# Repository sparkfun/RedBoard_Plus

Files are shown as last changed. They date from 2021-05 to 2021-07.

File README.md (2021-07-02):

SparkFun RedBoard Plus
============================

SparkFun RedBoard Plus (https://www.sparkfun.com/products/18158)

[*SparkFun RedBoard Plus (DEV-18158)*](https://www.sparkfun.com/products/18158)

At SparkFun we continually like to innovate, update, and improve even when it comes to our very own development boards. The SparkFun RedBoard Plus is an Arduino-compatible development board that has everything you need in an Arduino Uno with *many* extra perks. The best part about the RedBoard Plus is that it utilizes our handy Qwiic Connect System which means no soldering or shields are required to connect it to the rest of your system!

We've applied every lesson we've learned about making a better Arduino Uno and created the RedBoard Plus! The SparkFun RedBoard Plus has all of the hardware peripherals you know and love: 22x Digital I/O pins with 6x PWM pins, 8x analog pins, UART, I<sup>2</sup>C, SPI, and external interrupts. We've also broken out the SDA, SCL and IOREF pins that showed up on the Arduino Uno R3 footprint, so the RedBoard Plus is compatible with future shields (if you choose to use them). Two additional analog pins are included for A6 and A7.

The USB-to-serial is now done with a *reversible* USB-C connector with through hole anchoring and the ubiquitous CH340G requiring fewer driver installs. The power portion of the RedBoard Plus has been optimized: we use the AP2112 3.3V voltage regulator to provide up to 600mA to daisy chain multiple Qwiic boards and sensors, with full thermal and reverse circuit protection, and added extra decoupling capacitance to increase the sensitivity of the ADC readings. We've also increased the PTC from 500mA to 2A. We've decreased the brightness of the power LED, pin 13 LED, and the TX/RX LEDs from blinding to just perfect.

We've included 3.3V voltage translation and a [Qwiic connector](https://www.sparkfun.com/qwiic) to the edge of the board to allow for quick and seamless connection to our ever-growing line of I<sup>2</sup>C based [Qwiic products](https://www.sparkfun.com/qwiic#products). Jumpers are included on the board for the A4 and A5 pins which are tied directly to the I<sup>2</sup>C bus and can be used to disconnect the logic level converters from the pins. 

For more advanced users we've added an I/O voltage switch also known as the "Red Squirrel" switch (because they are the one [who petitioned for the mod](https://www.sparkfun.com/products/retired/15296#comment-5d78452ec6a6ff5bfc77dba7)). Now you can easily select the GPIO voltage between 3.3V or 5V with just your finger. This is extremely handy if you have a shield or 3.3V sensitive devices, such as an SPI interface, that needs protecting. Worried about accidentally flipping the switch? A piece of tape will lock it in place!

We include clearly labeled PTH holes alongside the standard female headers. This makes it very easy to solder wires in place for a secure connection to make your project 'backpack safe' once you get it working. Solder pads are included on the bottom of the board for USB data pins D+/D- so you can embed your RedBoard Plus into a project and run an external USB connection. We've increased the height of the reset button. This doesn't sound like much, but everyone who's touched it loves the improvement. 

The SparkFun RedBoard Plus can be programmed over a USB-C cable using the Arduino IDE: Just plug in the board, select "**Arduino UNO**" from the board menu and you're ready to upload code! You can power the SparkFun RedBoard Plus over USB or through the barrel jack. The on-board power regulator can handle anything from 7VDC to 15VDC. Check out the related items below for a compatible wall-wart power supply.

Not sure which Arduino or Arduino-compatible board is right for you? Check out our [Arduino Buying Guide](https://www.sparkfun.com/arduino_guide)!

Repository Contents
-------------------
* **/Documentation** - Data sheets, additional product information
* **/Hardware** - Eagle design files (.brd, .sch)
* **/Production** - Production panel files (.brd)

Documentation
--------------
* **[Hookup Guide](https://learn.sparkfun.com/tutorials/1758)** - Basic hookup guide for the RedBoard Plus.

License Information
-------------------

This product is _**open source**_! 

Please review the LICENSE.md file for license information. 

If you have any questions or concerns on licensing, please contact technical support on our [SparkFun forums](https://forum.sparkfun.com/viewforum.php?f=152).

Distributed as-is; no warranty is given.

- Your friends at SparkFun.

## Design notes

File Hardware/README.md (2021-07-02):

SparkFun RedBoard Plus Design Files
=====================================

The .sch and .brd files hare are Eagle CAD schematic and PCB design files from SparkFun Electronics.
A freeware version of Eagle can be found [here](http://www.cadsoftusa.com/download-eagle/freeware/).

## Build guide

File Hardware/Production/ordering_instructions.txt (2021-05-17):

panel size, 374x132mm
PCB thickness, 1.6mm
number of layers, 2
soldermask color, Red
silkscreen color, White
oz copper, 1oz
finish, HASL lead free
stencils, top
pcs per panel, 10
min trace width, 0.2540mm / 0.0100in
min drill size, 0.3810mm / 0.0150in

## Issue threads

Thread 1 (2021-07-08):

Cap C18 too far from CH340G vcc pin

Hooziw, 2021-07-08:
Use as decoupling cap, C18 is too far form chip vcc
and DTR wire has 10mil width, normal was 12mil.

makin-stuff, 2021-07-09:
@Hooziw Thanks for the input and good catch! This issue will be addressed in the next version of this board.

Closed 2021-07-09.

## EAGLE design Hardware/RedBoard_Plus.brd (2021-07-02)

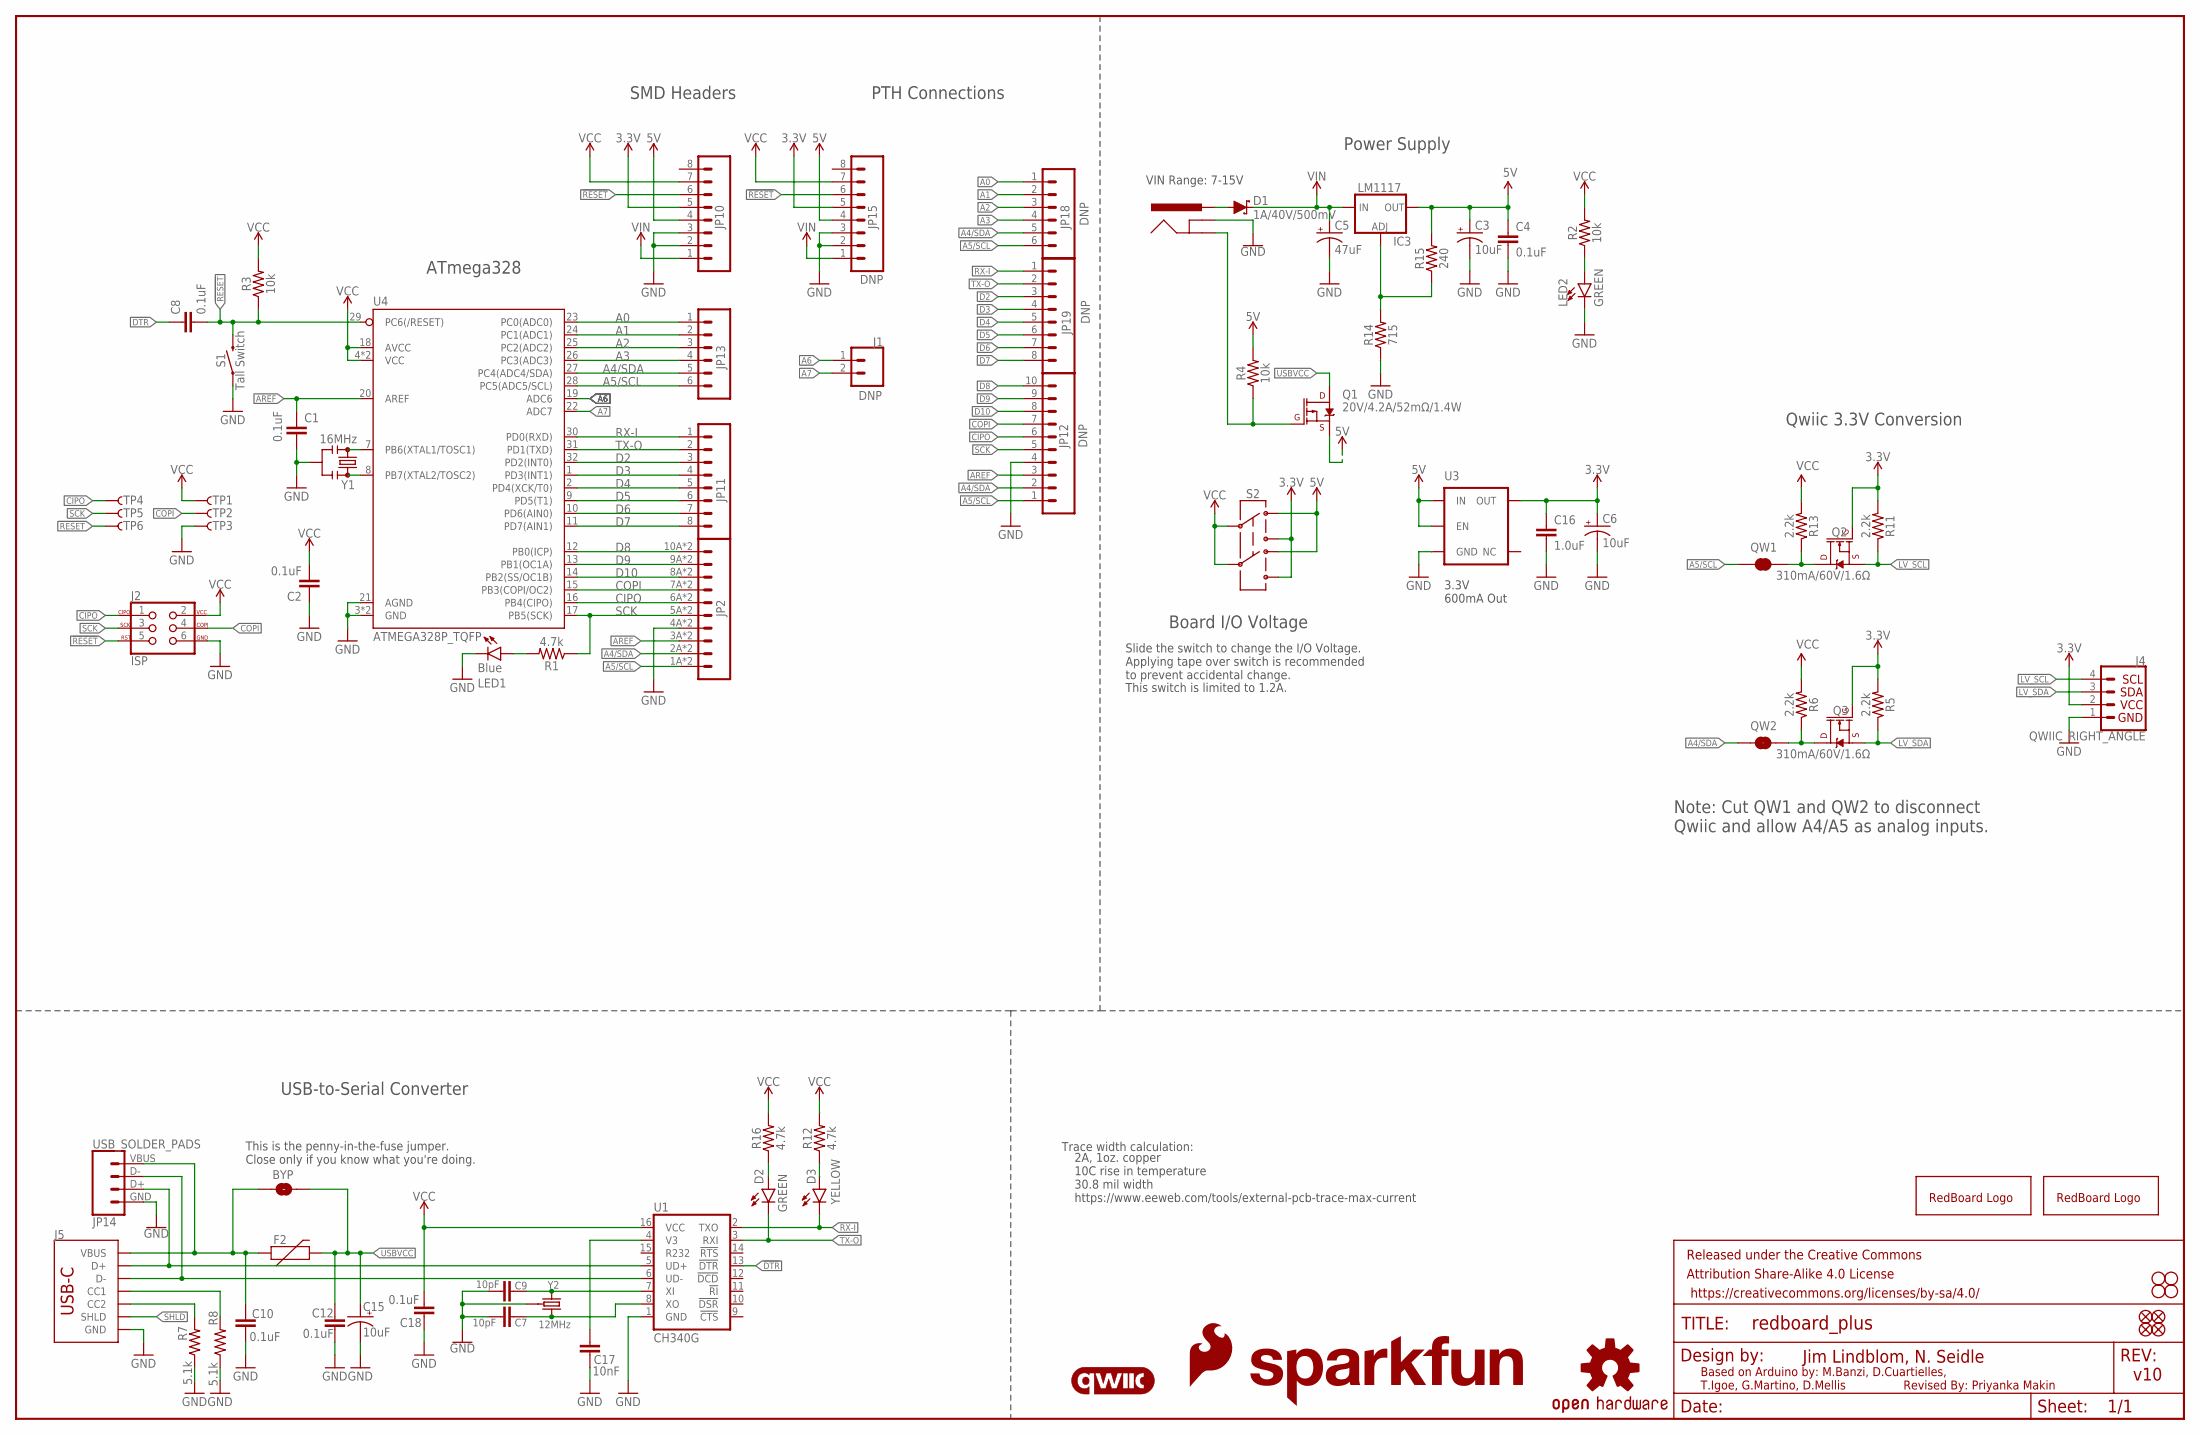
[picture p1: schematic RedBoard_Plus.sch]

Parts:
BYP: JUMPER-SMT_2_NO_SILK; SMT-JUMPER_2_NO_SILK
C1, C2, C4, C8, C10, C12, C18: 0.1uF; 0603
C3, C6, C15: 10uF; EIA3216
C5: 47uF; PANASONIC_D
C7, C9: 10pF; 0603
C16: 1.0uF; 0603
C17: 10nF; 0603
D1: 1A/40V/500mV; SMA-DIODE
D2: GREEN; LED-1206
D3: YELLOW; LED-1206-HIDDENSILK
F2: 6V/2A; 1210
FD1, FD2: FIDUCIAL1X2; FIDUCIAL-1X2
FRAME1: FRAME-LEDGER; CREATIVE_COMMONS
IC3: LM1117; SOT223
J1: DNP; 1X02_NO_SILK
J2: ISP; 2X3_SMT_POSTS
J3: 5.5x2.1mm Barrel; POWER_JACK_SMD
J4: QWIIC_RIGHT_ANGLE; JST04_1MM_RA
J5: USB Female Type C Connector; USB-C-16P-2LAYER-PADS
JP1: SFE_LOGO_NAME.1_INCH; SFE_LOGO_NAME_.1
JP2: CONN_10SMD_COMBO-FEMALE; 1X10_SMD_COMBINED
JP3, JP4, JP5, JP6: STAND-OFFTIGHT; STAND-OFF-TIGHT
JP7: SFE_LOGO_FLAME.1_INCH; SFE_LOGO_FLAME_.1
JP8, JP9: FIDUCIAL1X2; FIDUCIAL-1X2
JP10: CONN_08SMD-COMBO-FEMALE; 1X08_SMD_COMBINED
JP11: JP11; 1X08_SMD_COMBINED
JP12: DNP; 1X10_NO_SILK
JP13: CONN_06SMD-STRAIGHT-COMBO-FEMALE; 1X06_SMD_STRAIGHT_COMBO
JP14: USB_SOLDER_PADS; USB-SOLDER-PADS
JP15, JP19: DNP; 1X08_NO_SILK
JP18: DNP; 1X06_NO_SILK
LED1: Blue; LED-1206-HIDDENSILK
LED2: GREEN; LED-1206
LOGO1: QWIIC_LOGO_5MM; QWIIC_5MM
Q1: 20V/4.2A/52mΩ/1.4W; SOT23-3
Q2, Q3: 310mA/60V/1.6Ω; SOT323
QW1, QW2: JUMPER-SMT_2_NC_TRACE_SILK; SMT-JUMPER_2_NC_TRACE_SILK
R1, R12, R16: 4.7k; 0603
R2, R3, R4: 10k; 0603
R5, R6, R11, R13: 2.2k; 0603
R7, R8: 5.1k; 0603
R14: 715; 0603
R15: 240; 0603
S1: Tall Switch; TACTILE_SWITCH_SMD_5.2MM
S2: SWITCH-DPDT-SMD-AYZ0202; SWITCH_DPDT_SMD_AYZ0202
TP1, TP2, TP3, TP4, TP5, TP6: TP-3x5; PAD.03X.05
U1: CH340G; SO016
U3: 3.3V; SOT23-5
U4: ATMEGA328P_TQFP; TQFP32-08
U$1, U$3: REDBOARD_LOGO
U$16: OSHW-LOGOS; OSHW-LOGO-S
Y1: 16MHz; RESONATOR-SMD-3.2X1.3
Y2: 12MHz; CRYSTAL-SMD-3.2X2.5MM

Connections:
3.3V: C6.+, C16.1, J4.2, JP10.5, JP15.5, Q2.1 (G), Q3.1 (G), R5.2, R11.2, S2.1, S2.4, U3.5 (OUT)
5V: C3.+, C4.1, IC3.2 (OUT), IC3.4 (OUT), JP10.4, JP15.4, Q1.2 (S), R4.2, R15.2, S2.3, S2.6, U3.1 (IN), U3.3 (EN)
!DTR!: C8.1, U1.13 (!DTR)
!RESET: C8.2, J2.5, JP10.6, JP15.6, R3.1, S1.3 (2), S1.4 (2), TP6.P$1, U4.29 (PC6(/RESET))
A0: JP13.1, JP18.1, U4.23 (PC0(ADC0))
A1: JP13.2, JP18.2, U4.24 (PC1(ADC1))
A2: JP13.3, JP18.3, U4.25 (PC2(ADC2))
A3: JP13.4, JP18.4, U4.26 (PC3(ADC3))
A4/SDA: JP2.2A (2), JP2.2B (2), JP12.2, JP13.5, JP18.5, QW2.1, U4.27 (PC4(ADC4/SDA))
A5/SCL: JP2.1A (1), JP2.1B (1), JP12.1, JP13.6, JP18.6, QW1.1, U4.28 (PC5(ADC5/SCL))
A6: J1.1, U4.19 (ADC6)
A7: J1.2, U4.22 (ADC7)
AREF: C1.1, JP2.3A (3), JP2.3B (3), JP12.3, U4.20 (AREF)
CC1: J5.A5 (CC1), R8.2
CC2: J5.B5 (CC2), R7.2
CIPO: J2.1, JP2.6A (6), JP2.6B (6), JP12.6, TP4.P$1, U4.16 (PB4(CIPO))
COPI: J2.4, JP2.7A (7), JP2.7B (7), JP12.7, TP2.P$1, U4.15 (PB3(COPI/OC2))
D2: JP11.3, JP19.3, U4.32 (PD2(INT0))
D3: JP11.4, JP19.4, U4.1 (PD3(INT1))
D4: JP11.5, JP19.5, U4.2 (PD4(XCK/T0))
D5: JP11.6, JP19.6, U4.9 (PD5(T1))
D6: JP11.7, JP19.7, U4.10 (PD6(AIN0))
D7: JP11.8, JP19.8, U4.11 (PD7(AIN1))
D8: JP2.10A (10), JP2.10B (10), JP12.10, U4.12 (PB0(ICP))
D9: JP2.9A (9), JP2.9B (9), JP12.9, U4.13 (PB1(OC1A))
D10: JP2.8A (8), JP2.8B (8), JP12.8, U4.14 (PB2(SS/OC1B))
D+: J5.A6 (D+), J5.B6 (D+), JP14.D+ (3), U1.5 (UD+)
D-: J5.A7 (D-), J5.B7 (D-), JP14.D- (2), U1.6 (UD-)
GND: C1.2, C2.1, C3.-, C4.2, C5.-, C6.-, C7.2, C9.2, C10.2, C12.2, C15.-, C16.2, C17.2, C18.2, J2.6, J3.GND (GNDBREAK), J4.1, J5.GND, J5.GND2 (GND), JP2.4A (4), JP2.4B (4), JP10.2, JP10.3, JP12.4, JP14.GND (4), JP15.2, JP15.3, LED1.C, LED2.C, R7.1, R8.1, R14.1, S1.1, S1.2 (1), TP3.P$1, U1.1 (GND), U3.2 (GND), U4.3 (GND), U4.5 (GND), U4.21 (AGND), Y1.2, Y2.2 (GND), Y2.4 (GND)
INSERT: J3.P$4 (GND), Q1.1 (G), R4.1
LV_SCL: J4.4, Q2.2 (S), R11.1
LV_SDA: J4.3, Q3.2 (S), R5.1
unnamed: LED1.A, R1.2
unnamed: LED2.A, R2.1
unnamed: U4.7 (PB6(XTAL1/TOSC1)), Y1.1
unnamed: U4.8 (PB7(XTAL2/TOSC2)), Y1.3
unnamed: D2.A, R16.1
unnamed: C17.1, U1.4 (V3)
unnamed: Q2.3 (D), QW1.2, R13.1
unnamed: C9.1, U1.7 (XI), Y2.1
unnamed: D3.A, R12.1
unnamed: C7.1, U1.8 (XO), Y2.3 (2)
unnamed: IC3.1 (ADJ), R14.2, R15.1
unnamed: Q3.3 (D), QW2.2, R6.1
PWRIN: D1.A, J3.VIN0 (PWR)
RX-I: D3.C, JP11.1, JP19.1, U1.2 (TXO), U4.30 (PD0(RXD))
SCK: J2.3, JP2.5A (5), JP2.5B (5), JP12.5, R1.1, TP5.P$1, U4.17 (PB5(SCK))
SHLD: J5.SHLD1 (SHLD), J5.SHLD2 (SHLD), J5.SHLD3 (SHLD), J5.SHLD4 (SHLD)
TX-O: D2.C, JP11.2, JP19.2, U1.3 (RXI), U4.31 (PD1(TXD))
USBVCC: BYP.2, C12.1, C15.+, F2.2, Q1.3 (D)
VCC: C2.2, C18.1, J2.2, JP10.7, JP15.7, R2.2, R3.2, R6.2, R12.2, R13.2, R16.2, S2.2, S2.5, TP1.P$1, U1.16 (VCC), U4.4 (VCC), U4.6 (VCC), U4.18 (AVCC)
VIN: C5.+, D1.C, IC3.3 (IN), JP10.1, JP15.1
VUSB: BYP.1, C10.1, F2.1, J5.VBUS1 (VBUS), J5.VBUS2 (VBUS), JP14.VBUS (1)

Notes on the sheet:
Power Supply
ATmega328
USB-to-Serial Converter
Based on Arduino by: M.Banzi, D.Cuartielles, T.Igoe, G.Martino, D.Mellis
Jim Lindblom, N. Seidle
v10
VIN Range: 7-15V
3.3V 600mA Out
Board I/O Voltage
Slide the switch to change the I/O Voltage. Applying tape over switch is recommended to prevent accidental change.
Qwiic 3.3V Conversion
Note: Cut QW1 and QW2 to disconnect Qwiic and allow A4/A5 as analog inputs.
This is the penny-in-the-fuse jumper. Close only if you know what you're doing.
Trace width calculation:
2A, 1oz. copper 10C rise in temperature 30.8 mil width https://www.eeweb.com/tools/external-pcb-trace-max-current
This switch is limited to 1.2A.
PTH Connections
SMD Headers
Revised By: Priyanka Makin

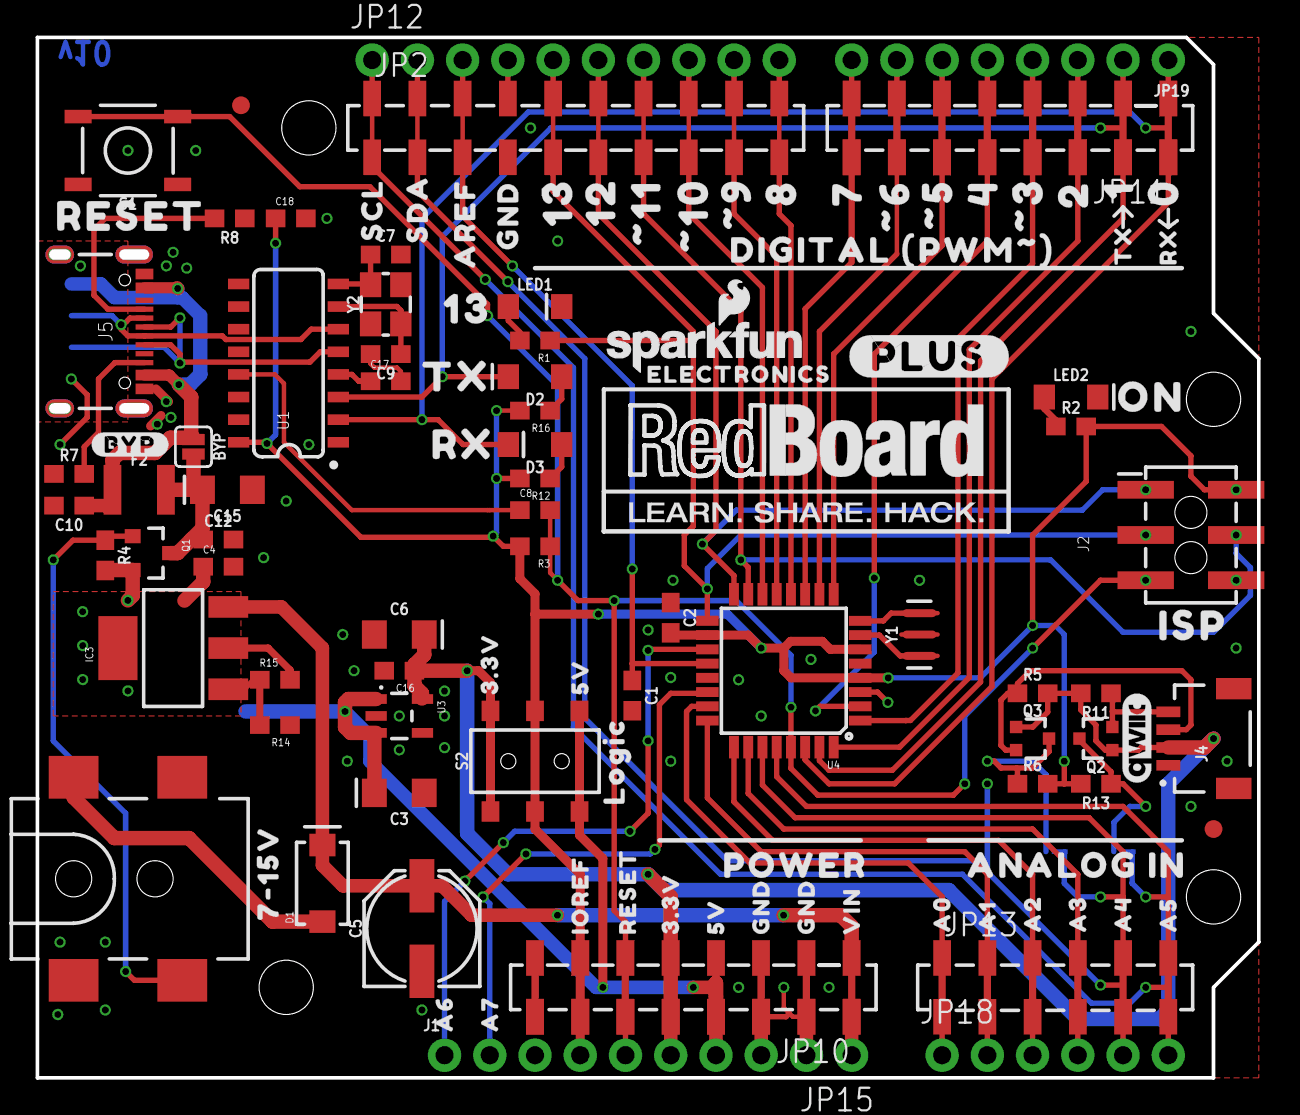
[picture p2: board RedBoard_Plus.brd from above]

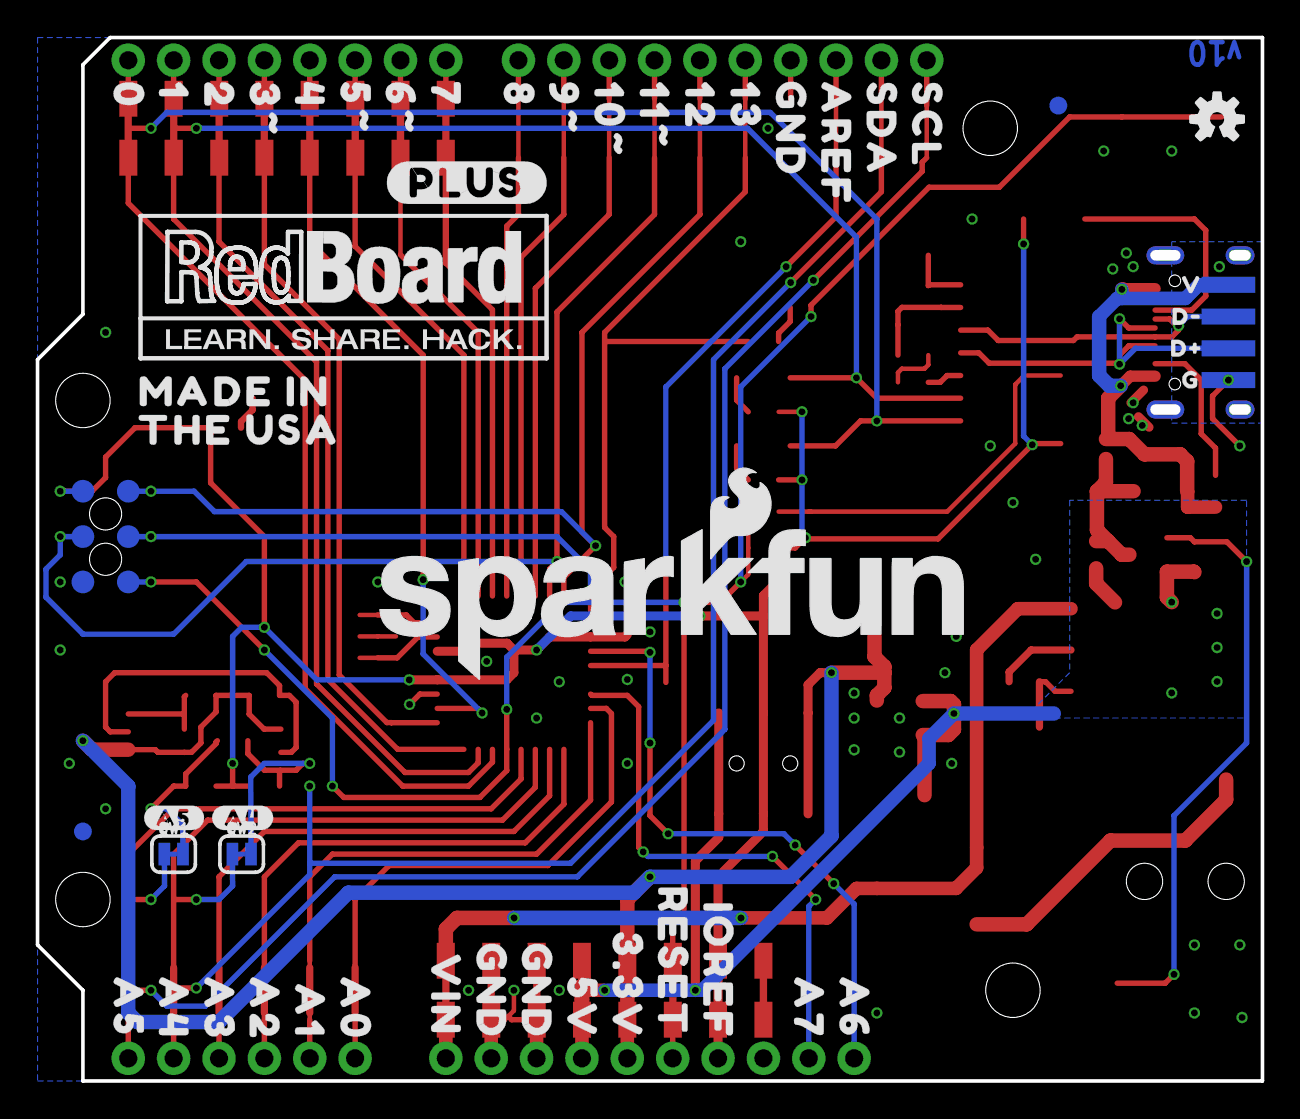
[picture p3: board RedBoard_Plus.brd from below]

Board: 2 copper layers, 68.6 x 58.4 mm, 179 parts (57 on the bottom side), 53 nets.

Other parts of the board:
U$2: _D#0
U$4: V0
U$9: 10#0
U$10: G0
U$11: LOGIC0
U$12: D#0
U$13, U$95: _RESET0
U$14: #BYP#0
U$17: 7#15V0
U$18: _AREF0
U$19: _SCL0
U$20: _SDA0
U$21: 11#0
U$22, U$77: 130
U$23, U$76: 120
U$24: #110
U$25: #100
U$26: #90
U$27, U$72: 80
U$28, U$71: 70
U$29: #60
U$30: #50
U$31, U$68: 40
U$32: #30
U$33, U$66: 20
U$34, U$65: 10
U$35, U$64: 00
U$36: TX0
U$37: RX0
U$38: DIGITAL_##PWM####_0
U$39: 13_0
U$40: _TX0
U$41: _RX0
U$42: _GND0
U$43, U$51: 3#3V0
U$44, U$52: 5V0
U$45: ON0
U$46: ISP0
U$47: POWER0
U$48: ANALOG_IN0
U$49: IOREF0
U$50: RESET0
U$53, U$54: GND0
U$55: VIN0
U$56: A00
U$57: A10
U$58: A20
U$59: A30
U$60: A40
U$61: A50
U$62: A60
U$63: A70
U$67: 3#0
U$69: 5#0
U$70: 6#0
U$73: 9#0
U$78: SFE_LOGO_NAME_.3
U$79: AREF0
U$80: SDA0
U$81: SCL0
U$82: MADE_IN0
U$83: THE_USA0
U$84: _A40
U$85, U$99, U$107: _GND_0
U$86: _A30
U$87: _A20
U$88: _A10
U$89: _A00
U$90: _VIN0
U$93: _5V0
U$94: _3#3V0
U$96: _IOREF0
U$97: _A60
U$98: _A70
U$100, U$103: #PLUS#0
U$101: SFE_LOGO_FLAME_.2
U$102: _A50
U$104: ELECTRONICS0
U$105: #A4#0
U$106: #A5#0

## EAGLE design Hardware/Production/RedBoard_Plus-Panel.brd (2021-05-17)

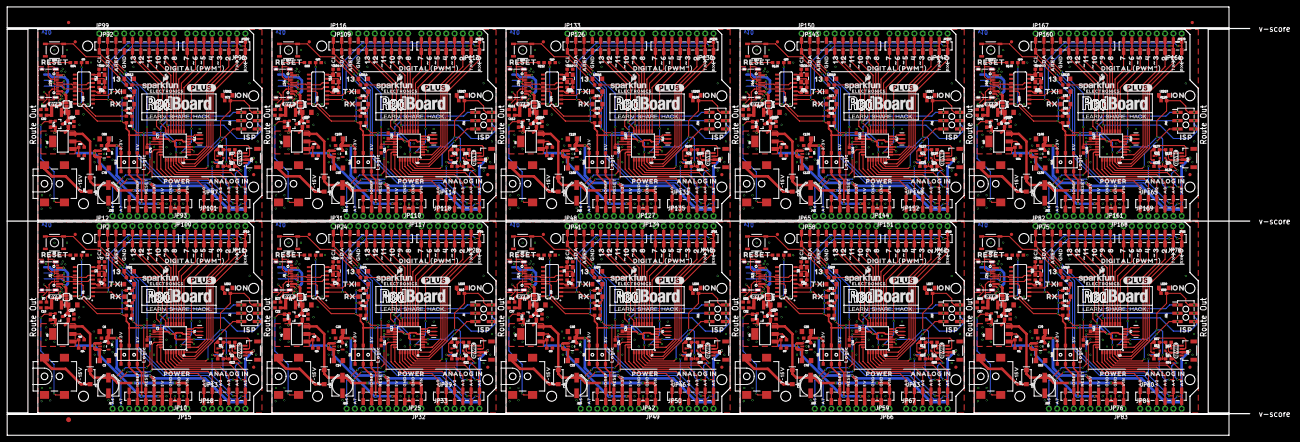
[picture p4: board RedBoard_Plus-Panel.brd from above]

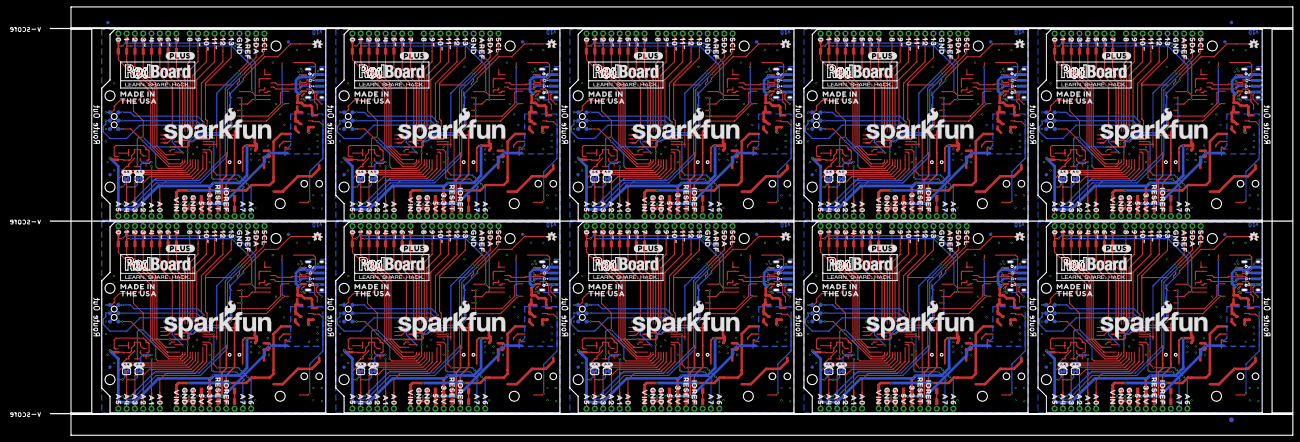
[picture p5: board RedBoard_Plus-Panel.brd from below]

Board: 2 copper layers, 380.2 x 131.1 mm, 1786 parts (573 on the bottom side), 530 nets.

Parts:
BYP, BYP1, BYP2, BYP3, BYP4, BYP5, BYP6, BYP7, BYP8, BYP9: JUMPER-SMT_2_NO_SILK; SMT-JUMPER_2_NO_SILK
C1, C2, C4, C8, C10, C11, C12, C13, C18, C19, C21, C22, C23, C28, C31, C32, C34, C36, C37, C38, C43, C46, C47, C49, C51, C52, C53, C58, C61, C62, C64, C66, C67, C68, C73, C76, C77, C79, C81, C82, C83, C88, C91, C92, C94, C96, C97, C98, C103, C106, C107, C109, C111, C112, C113, C118, C121, C122, C124, C126, C127, C128, C133, C136, C137, C139, C141, C142, C143, C148: 0.1uF; 0603
C3, C6, C14, C15, C24, C25, C33, C39, C40, C48, C54, C55, C63, C69, C70, C78, C84, C85, C93, C99, C100, C108, C114, C115, C123, C129, C130, C138, C144, C145: 10uF; EIA3216
C5, C20, C35, C50, C65, C80, C95, C110, C125, C140: 47uF; PANASONIC_D
C7, C9, C29, C30, C44, C45, C59, C60, C74, C75, C89, C90, C104, C105, C119, C120, C134, C135, C149, C150: 10pF; 0603
C16, C26, C41, C56, C71, C86, C101, C116, C131, C146: 1.0uF; 0603
C17, C27, C42, C57, C72, C87, C102, C117, C132, C147: 10nF; 0603
D1, D4, D7, D10, D13, D16, D19, D22, D25, D28: 1A/40V/500mV; SMA-DIODE
D2, D6, D9, D12, D15, D18, D21, D24, D27, D30: GREEN; LED-1206
D3, D5, D8, D11, D14, D17, D20, D23, D26, D29: YELLOW; LED-1206-HIDDENSILK
E$1, E$2, E$3, E$4: FIDUCIAL-1X2
E$5, E$6: FIDUCIAL-1.5X3
F1, F2, F3, F4, F5, F6, F7, F8, F9, F10: 6V/2A; 1210
FD1, FD2, FD3, FD4, FD5, FD6, FD7, FD8, FD9, FD10, FD11, FD12, FD13, FD14, FD15, FD16, FD17, FD18, FD19, FD20: FIDUCIAL1X2; FIDUCIAL-1X2
IC1, IC2, IC3, IC4, IC5, IC6, IC7, IC8, IC9, IC10: LM1117; SOT223
J1, J10, J15, J20, J25, J30, J35, J40, J45, J50: DNP; 1X02_NO_SILK
J2, J6, J11, J16, J21, J26, J31, J36, J41, J46: ISP; 2X3_SMT_POSTS
J3, J7, J12, J17, J22, J27, J32, J37, J42, J47: 5.5x2.1mm Barrel; POWER_JACK_SMD
J4, J8, J13, J18, J23, J28, J33, J38, J43, J48: QWIIC_RIGHT_ANGLE; JST04_1MM_RA
J5, J9, J14, J19, J24, J29, J34, J39, J44, J49: USB Female Type C Connector; USB-C-16P-2LAYER-PADS
JP1, JP26, JP43, JP60, JP77, JP94, JP111, JP128, JP145, JP162: SFE_LOGO_NAME.1_INCH; SFE_LOGO_NAME_.1
JP2, JP24, JP41, JP58, JP75, JP92, JP109, JP126, JP143, JP160: 1X10_SMD_COMBINED
JP3, JP4, JP5, JP6, JP16, JP17, JP20, JP21, JP35, JP36, JP37, JP38, JP52, JP53, JP54, JP55, JP69, JP70, JP71, JP72, JP86, JP87, JP88, JP89, JP103, JP104, JP105, JP106, JP120, JP121, JP122, JP123, JP137, JP138, JP139, JP140, JP154, JP155, JP156, JP157: STAND-OFFTIGHT; STAND-OFF-TIGHT
JP7, JP27, JP44, JP61, JP78, JP95, JP112, JP129, JP146, JP163: SFE_LOGO_FLAME.1_INCH; SFE_LOGO_FLAME_.1
JP8, JP9, JP22, JP23, JP39, JP40, JP56, JP57, JP73, JP74, JP90, JP91, JP107, JP108, JP124, JP125, JP141, JP142, JP158, JP159: FIDUCIAL1X2; FIDUCIAL-1X2
JP10, JP25, JP42, JP59, JP76, JP93, JP110, JP127, JP144, JP161: 1X08_SMD_COMBINED
JP11, JP28, JP45, JP62, JP79, JP96, JP113, JP130, JP147, JP164: JP11; 1X08_SMD_COMBINED
JP12, JP31, JP48, JP65, JP82, JP99, JP116, JP133, JP150, JP167: DNP; 1X10_NO_SILK
JP13, JP29, JP46, JP63, JP80, JP97, JP114, JP131, JP148, JP165: 1X06_SMD_STRAIGHT_COMBO
JP14, JP30, JP47, JP64, JP81, JP98, JP115, JP132, JP149, JP166: USB_SOLDER_PADS; USB-SOLDER-PADS
JP15, JP19, JP32, JP34, JP49, JP51, JP66, JP68, JP83, JP85, JP100, JP102, JP117, JP119, JP134, JP136, JP151, JP153, JP168, JP170: DNP; 1X08_NO_SILK
JP18, JP33, JP50, JP67, JP84, JP101, JP118, JP135, JP152, JP169: DNP; 1X06_NO_SILK
LED1, LED4, LED6, LED8, LED10, LED12, LED14, LED16, LED18, LED20: Blue; LED-1206-HIDDENSILK
LED2, LED3, LED5, LED7, LED9, LED11, LED13, LED15, LED17, LED19: GREEN; LED-1206
LOGO1, LOGO2, LOGO3, LOGO4, LOGO5, LOGO6, LOGO7, LOGO8, LOGO9, LOGO10: QWIIC_LOGO_5MM; QWIIC_5MM
Q1, Q4, Q7, Q10, Q13, Q16, Q19, Q22, Q25, Q28: 20V/4.2A/52mΩ/1.4W; SOT23-3
Q2, Q3, Q5, Q6, Q8, Q9, Q11, Q12, Q14, Q15, Q17, Q18, Q20, Q21, Q23, Q24, Q26, Q27, Q29, Q30: 310mA/60V/1.6Ω; SOT323
QW1, QW2, QW3, QW4, QW5, QW6, QW7, QW8, QW9, QW10, QW11, QW12, QW13, QW14, QW15, QW16, QW17, QW18, QW19, QW20: JUMPER-SMT_2_NC_TRACE_SILK; SMT-JUMPER_2_NC_TRACE_SILK
R1, R9, R12, R16, R23, R24, R29, R37, R38, R43, R51, R52, R57, R65, R66, R71, R79, R80, R85, R93, R94, R99, R107, R108, R113, R121, R122, R127, R135, R136: 4.7k; 0603
R2, R3, R4, R10, R17, R18, R30, R31, R32, R44, R45, R46, R58, R59, R60, R72, R73, R74, R86, R87, R88, R100, R101, R102, R114, R115, R116, R128, R129, R130: 10k; 0603
R5, R6, R11, R13, R21, R22, R25, R26, R35, R36, R39, R40, R49, R50, R53, R54, R63, R64, R67, R68, R77, R78, R81, R82, R91, R92, R95, R96, R105, R106, R109, R110, R119, R120, R123, R124, R133, R134, R137, R138: 2.2k; 0603
R7, R8, R27, R28, R41, R42, R55, R56, R69, R70, R83, R84, R97, R98, R111, R112, R125, R126, R139, R140: 5.1k; 0603
R14, R19, R33, R47, R61, R75, R89, R103, R117, R131: 715; 0603
R15, R20, R34, R48, R62, R76, R90, R104, R118, R132: 240; 0603
S1, S3, S5, S7, S9, S11, S13, S15, S17, S19: Tall Switch; TACTILE_SWITCH_SMD_5.2MM
S2, S4, S6, S8, S10, S12, S14, S16, S18, S20: SWITCH_DPDT_SMD_AYZ0202
TP1, TP2, TP3, TP4, TP5, TP6, TP7, TP8, TP9, TP10, TP11, TP12, TP13, TP14, TP15, TP16, TP17, TP18, TP19, TP20, TP21, TP22, TP23, TP24, TP25, TP26, TP27, TP28, TP29, TP30, TP31, TP32, TP33, TP34, TP35, TP36, TP37, TP38, TP39, TP40, TP41, TP42, TP43, TP44, TP45, TP46, TP47, TP48, TP49, TP50, TP51, TP52, TP53, TP54, TP55, TP56, TP57, TP58, TP59, TP60: TP-3x5; PAD.03X.05
U1, U6, U9, U12, U15, U18, U21, U24, U27, U30: CH340G; SO016
U2, U4, U7, U10, U13, U16, U19, U22, U25, U28: ATMEGA328P_TQFP; TQFP32-08
U3, U5, U8, U11, U14, U17, U20, U23, U26, U29: 3.3V; SOT23-5
U$1, U$3, U$164, U$165, U$262, U$263, U$360, U$361, U$458, U$459, U$556, U$557, U$654, U$655, U$752, U$753, U$850, U$851, U$948, U$949: REDBOARD_LOGO
U$2, U$162, U$260, U$358, U$456, U$554, U$652, U$750, U$848, U$946: _D#0
U$4, U$160, U$258, U$356, U$454, U$552, U$650, U$748, U$846, U$944: V0
U$5, U$16, U$197, U$295, U$393, U$491, U$589, U$687, U$785, U$883: OSHW-LOGOS; OSHW-LOGO-S
U$6, U$14, U$198, U$296, U$394, U$492, U$590, U$688, U$786, U$884: #BYP#0
U$7, U$17, U$199, U$297, U$395, U$493, U$591, U$689, U$787, U$885: 7#15V0
U$8, U$22, U$77, U$154, U$200, U$252, U$298, U$350, U$396, U$448, U$494, U$546, U$592, U$644, U$690, U$742, U$788, U$840, U$886, U$938: 130
U$9, U$195, U$293, U$391, U$489, U$587, U$685, U$783, U$881, U$979: 10#0
U$10, U$163, U$261, U$359, U$457, U$555, U$653, U$751, U$849, U$947: G0
U$11, U$190, U$288, U$386, U$484, U$582, U$680, U$778, U$876, U$974: LOGIC0
U$12, U$161, U$259, U$357, U$455, U$553, U$651, U$749, U$847, U$945: D#0
U$13, U$95, U$177, U$181, U$275, U$279, U$373, U$377, U$471, U$475, U$569, U$573, U$667, U$671, U$765, U$769, U$863, U$867, U$961, U$965: _RESET0
U$15, U$23, U$76, U$153, U$201, U$251, U$299, U$349, U$397, U$447, U$495, U$545, U$593, U$643, U$691, U$741, U$789, U$839, U$887, U$937: 120
U$18, U$182, U$280, U$378, U$476, U$574, U$672, U$770, U$868, U$966: _AREF0
U$19, U$183, U$281, U$379, U$477, U$575, U$673, U$771, U$869, U$967: _SCL0
U$20, U$184, U$282, U$380, U$478, U$576, U$674, U$772, U$870, U$968: _SDA0
U$21, U$196, U$294, U$392, U$490, U$588, U$686, U$784, U$882, U$980: 11#0
U$24, U$74, U$202, U$300, U$398, U$496, U$594, U$692, U$790, U$888: #110
U$25, U$75, U$203, U$301, U$399, U$497, U$595, U$693, U$791, U$889: #100
U$26, U$91, U$204, U$302, U$400, U$498, U$596, U$694, U$792, U$890: #90
U$27, U$72, U$92, U$151, U$205, U$249, U$303, U$347, U$401, U$445, U$499, U$543, U$597, U$641, U$695, U$739, U$793, U$837, U$891, U$935: 80
U$28, U$71, U$108, U$150, U$206, U$248, U$304, U$346, U$402, U$444, U$500, U$542, U$598, U$640, U$696, U$738, U$794, U$836, U$892, U$934: 70
U$29, U$109, U$207, U$305, U$403, U$501, U$599, U$697, U$795, U$893: #60
U$30, U$110, U$208, U$306, U$404, U$502, U$600, U$698, U$796, U$894: #50
U$31, U$68, U$111, U$147, U$209, U$245, U$307, U$343, U$405, U$441, U$503, U$539, U$601, U$637, U$699, U$735, U$797, U$833, U$895, U$931: 40
U$32, U$112, U$210, U$308, U$406, U$504, U$602, U$700, U$798, U$896: #30
U$33, U$66, U$113, U$145, U$211, U$243, U$309, U$341, U$407, U$439, U$505, U$537, U$603, U$635, U$701, U$733, U$799, U$831, U$897, U$929: 20
U$34, U$65, U$114, U$144, U$212, U$242, U$310, U$340, U$408, U$438, U$506, U$536, U$604, U$634, U$702, U$732, U$800, U$830, U$898, U$928: 10
U$35, U$64, U$115, U$143, U$213, U$241, U$311, U$339, U$409, U$437, U$507, U$535, U$605, U$633, U$703, U$731, U$801, U$829, U$899, U$927: 00
U$36, U$116, U$214, U$312, U$410, U$508, U$606, U$704, U$802, U$900: TX0
U$37, U$117, U$215, U$313, U$411, U$509, U$607, U$705, U$803, U$901: RX0
U$38, U$118, U$216, U$314, U$412, U$510, U$608, U$706, U$804, U$902: DIGITAL_##PWM####_0
U$39, U$119, U$217, U$315, U$413, U$511, U$609, U$707, U$805, U$903: 13_0
U$40, U$120, U$218, U$316, U$414, U$512, U$610, U$708, U$806, U$904: _TX0
U$41, U$121, U$219, U$317, U$415, U$513, U$611, U$709, U$807, U$905: _RX0
U$42, U$191, U$289, U$387, U$485, U$583, U$681, U$779, U$877, U$975: _GND0
U$43, U$51, U$122, U$130, U$220, U$228, U$318, U$326, U$416, U$424, U$514, U$522, U$612, U$620, U$710, U$718, U$808, U$816, U$906, U$914: 3#3V0
U$44, U$52, U$123, U$131, U$221, U$229, U$319, U$327, U$417, U$425, U$515, U$523, U$613, U$621, U$711, U$719, U$809, U$817, U$907, U$915: 5V0
U$45, U$124, U$222, U$320, U$418, U$516, U$614, U$712, U$810, U$908: ON0
U$46, U$125, U$223, U$321, U$419, U$517, U$615, U$713, U$811, U$909: ISP0
U$47, U$126, U$224, U$322, U$420, U$518, U$616, U$714, U$812, U$910: POWER0
U$48, U$127, U$225, U$323, U$421, U$519, U$617, U$715, U$813, U$911: ANALOG_IN0
U$49, U$128, U$226, U$324, U$422, U$520, U$618, U$716, U$814, U$912: IOREF0
U$50, U$129, U$227, U$325, U$423, U$521, U$619, U$717, U$815, U$913: RESET0
U$53, U$54, U$132, U$133, U$230, U$231, U$328, U$329, U$426, U$427, U$524, U$525, U$622, U$623, U$720, U$721, U$818, U$819, U$916, U$917: GND0
U$55, U$134, U$232, U$330, U$428, U$526, U$624, U$722, U$820, U$918: VIN0
U$56, U$135, U$233, U$331, U$429, U$527, U$625, U$723, U$821, U$919: A00
U$57, U$136, U$234, U$332, U$430, U$528, U$626, U$724, U$822, U$920: A10
U$58, U$137, U$235, U$333, U$431, U$529, U$627, U$725, U$823, U$921: A20
U$59, U$138, U$236, U$334, U$432, U$530, U$628, U$726, U$824, U$922: A30
U$60, U$139, U$237, U$335, U$433, U$531, U$629, U$727, U$825, U$923: A40
U$61, U$140, U$238, U$336, U$434, U$532, U$630, U$728, U$826, U$924: A50
U$62, U$141, U$239, U$337, U$435, U$533, U$631, U$729, U$827, U$925: A60
U$63, U$142, U$240, U$338, U$436, U$534, U$632, U$730, U$828, U$926: A70
U$67, U$146, U$244, U$342, U$440, U$538, U$636, U$734, U$832, U$930: 3#0
U$69, U$148, U$246, U$344, U$442, U$540, U$638, U$736, U$834, U$932: 5#0
U$70, U$149, U$247, U$345, U$443, U$541, U$639, U$737, U$835, U$933: 6#0
U$73, U$152, U$250, U$348, U$446, U$544, U$642, U$740, U$838, U$936: 9#0
U$78, U$166, U$264, U$362, U$460, U$558, U$656, U$754, U$852, U$950: SFE_LOGO_NAME_.3
U$79, U$155, U$253, U$351, U$449, U$547, U$645, U$743, U$841, U$939: AREF0
U$80, U$156, U$254, U$352, U$450, U$548, U$646, U$744, U$842, U$940: SDA0
U$81, U$157, U$255, U$353, U$451, U$549, U$647, U$745, U$843, U$941: SCL0
U$82, U$158, U$256, U$354, U$452, U$550, U$648, U$746, U$844, U$942: MADE_IN0
U$83, U$159, U$257, U$355, U$453, U$551, U$649, U$747, U$845, U$943: THE_USA0
U$84, U$169, U$267, U$365, U$463, U$561, U$659, U$757, U$855, U$953: _A40
U$85, U$99, U$107, U$192, U$193, U$194, U$290, U$291, U$292, U$388, U$389, U$390, U$486, U$487, U$488, U$584, U$585, U$586, U$682, U$683, U$684, U$780, U$781, U$782, U$878, U$879, U$880, U$976, U$977, U$978: _GND_0
U$86, U$170, U$268, U$366, U$464, U$562, U$660, U$758, U$856, U$954: _A30
U$87, U$171, U$269, U$367, U$465, U$563, U$661, U$759, U$857, U$955: _A20
U$88, U$172, U$270, U$368, U$466, U$564, U$662, U$760, U$858, U$956: _A10
U$89, U$173, U$271, U$369, U$467, U$565, U$663, U$761, U$859, U$957: _A00
U$90, U$174, U$272, U$370, U$468, U$566, U$664, U$762, U$860, U$958: _VIN0
U$93, U$175, U$273, U$371, U$469, U$567, U$665, U$763, U$861, U$959: _5V0
U$94, U$176, U$274, U$372, U$470, U$568, U$666, U$764, U$862, U$960: _3#3V0
U$96, U$178, U$276, U$374, U$472, U$570, U$668, U$766, U$864, U$962: _IOREF0
U$97, U$179, U$277, U$375, U$473, U$571, U$669, U$767, U$865, U$963: _A60
U$98, U$180, U$278, U$376, U$474, U$572, U$670, U$768, U$866, U$964: _A70
U$100, U$103, U$185, U$186, U$283, U$284, U$381, U$382, U$479, U$480, U$577, U$578, U$675, U$676, U$773, U$774, U$871, U$872, U$969, U$970: #PLUS#0
U$101, U$167, U$265, U$363, U$461, U$559, U$657, U$755, U$853, U$951: SFE_LOGO_FLAME_.2
U$102, U$168, U$266, U$364, U$462, U$560, U$658, U$756, U$854, U$952: _A50
U$104, U$187, U$285, U$383, U$481, U$579, U$677, U$775, U$873, U$971: ELECTRONICS0
U$105, U$188, U$286, U$384, U$482, U$580, U$678, U$776, U$874, U$972: #A4#0
U$106, U$189, U$287, U$385, U$483, U$581, U$679, U$777, U$875, U$973: #A5#0
Y1, Y3, Y5, Y7, Y9, Y11, Y13, Y15, Y17, Y19: 16MHz; RESONATOR-SMD-3.2X1.3
Y2, Y4, Y6, Y8, Y10, Y12, Y14, Y16, Y18, Y20: 12MHz; CRYSTAL-SMD-3.2X2.5MM

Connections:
3.3V: C6.+, C16.1, J4.2, JP10.5, JP15.5, Q2.1, Q3.1, R5.2, R11.2, S2.1, S2.4, U3.5
3.3V1: C25.+, C26.1, J8.2, JP25.5, JP32.5, Q5.1, Q6.1, R21.2, R25.2, S4.1, S4.4, U5.5
3.3V2: C40.+, C41.1, J13.2, JP42.5, JP49.5, Q8.1, Q9.1, R35.2, R39.2, S6.1, S6.4, U8.5
3.3V3: C55.+, C56.1, J18.2, JP59.5, JP66.5, Q11.1, Q12.1, R49.2, R53.2, S8.1, S8.4, U11.5
3.3V4: C70.+, C71.1, J23.2, JP76.5, JP83.5, Q14.1, Q15.1, R63.2, R67.2, S10.1, S10.4, U14.5
3.3V5: C85.+, C86.1, J28.2, JP93.5, JP100.5, Q17.1, Q18.1, R77.2, R81.2, S12.1, S12.4, U17.5
3.3V6: C100.+, C101.1, J33.2, JP110.5, JP117.5, Q20.1, Q21.1, R91.2, R95.2, S14.1, S14.4, U20.5
3.3V7: C115.+, C116.1, J38.2, JP127.5, JP134.5, Q23.1, Q24.1, R105.2, R109.2, S16.1, S16.4, U23.5
3.3V8: C130.+, C131.1, J43.2, JP144.5, JP151.5, Q26.1, Q27.1, R119.2, R123.2, S18.1, S18.4, U26.5
3.3V9: C145.+, C146.1, J48.2, JP161.5, JP168.5, Q29.1, Q30.1, R133.2, R137.2, S20.1, S20.4, U29.5
5V: C3.+, C4.1, IC3.2, IC3.4, JP10.4, JP15.4, Q1.2, R4.2, R15.2, S2.3, S2.6, U3.1, U3.3
5V1: C14.+, C19.1, IC1.2, IC1.4, JP25.4, JP32.4, Q4.2, R18.2, R20.2, S4.3, S4.6, U5.1, U5.3
5V2: C33.+, C34.1, IC2.2, IC2.4, JP42.4, JP49.4, Q7.2, R32.2, R34.2, S6.3, S6.6, U8.1, U8.3
5V3: C48.+, C49.1, IC4.2, IC4.4, JP59.4, JP66.4, Q10.2, R46.2, R48.2, S8.3, S8.6, U11.1, U11.3
5V4: C63.+, C64.1, IC5.2, IC5.4, JP76.4, JP83.4, Q13.2, R60.2, R62.2, S10.3, S10.6, U14.1, U14.3
5V5: C78.+, C79.1, IC6.2, IC6.4, JP93.4, JP100.4, Q16.2, R74.2, R76.2, S12.3, S12.6, U17.1, U17.3
5V6: C93.+, C94.1, IC7.2, IC7.4, JP110.4, JP117.4, Q19.2, R88.2, R90.2, S14.3, S14.6, U20.1, U20.3
5V7: C108.+, C109.1, IC8.2, IC8.4, JP127.4, JP134.4, Q22.2, R102.2, R104.2, S16.3, S16.6, U23.1, U23.3
5V8: C123.+, C124.1, IC9.2, IC9.4, JP144.4, JP151.4, Q25.2, R116.2, R118.2, S18.3, S18.6, U26.1, U26.3
5V9: C138.+, C139.1, IC10.2, IC10.4, JP161.4, JP168.4, Q28.2, R130.2, R132.2, S20.3, S20.6, U29.1, U29.3
!DTR!: C8.1, U1.13
!DTR!1: C21.1, U6.13
!DTR!2: C36.1, U9.13
!DTR!3: C51.1, U12.13
!DTR!4: C66.1, U15.13
!DTR!5: C81.1, U18.13
!DTR!6: C96.1, U21.13
!DTR!7: C111.1, U24.13
!DTR!8: C126.1, U27.13
!DTR!9: C141.1, U30.13
!RESET: C8.2, J2.5, JP10.6, JP15.6, R3.1, S1.3, S1.4, TP6.P$1, U4.29
!RESET1: C21.2, J6.5, JP25.6, JP32.6, R17.1, S3.3, S3.4, TP12.P$1, U2.29
!RESET2: C36.2, J11.5, JP42.6, JP49.6, R31.1, S5.3, S5.4, TP18.P$1, U7.29
!RESET3: C51.2, J16.5, JP59.6, JP66.6, R45.1, S7.3, S7.4, TP24.P$1, U10.29
!RESET4: C66.2, J21.5, JP76.6, JP83.6, R59.1, S9.3, S9.4, TP30.P$1, U13.29
!RESET5: C81.2, J26.5, JP93.6, JP100.6, R73.1, S11.3, S11.4, TP36.P$1, U16.29
!RESET6: C96.2, J31.5, JP110.6, JP117.6, R87.1, S13.3, S13.4, TP42.P$1, U19.29
!RESET7: C111.2, J36.5, JP127.6, JP134.6, R101.1, S15.3, S15.4, TP48.P$1, U22.29
!RESET8: C126.2, J41.5, JP144.6, JP151.6, R115.1, S17.3, S17.4, TP54.P$1, U25.29
!RESET9: C141.2, J46.5, JP161.6, JP168.6, R129.1, S19.3, S19.4, TP60.P$1, U28.29
A0: JP13.1, JP18.1, U4.23
A1: JP13.2, JP18.2, U4.24
A2: JP13.3, JP18.3, U4.25
A3: JP13.4, JP18.4, U4.26
A4: JP29.1, JP33.1, U2.23
A4/SDA: JP2.2A, JP2.2B, JP12.2, JP13.5, JP18.5, QW2.1, U4.27
A4/SDA1: JP24.2A, JP24.2B, JP29.5, JP31.2, JP33.5, QW3.1, U2.27
A4/SDA2: JP41.2A, JP41.2B, JP46.5, JP48.2, JP50.5, QW5.1, U7.27
A4/SDA3: JP58.2A, JP58.2B, JP63.5, JP65.2, JP67.5, QW7.1, U10.27
A4/SDA4: JP75.2A, JP75.2B, JP80.5, JP82.2, JP84.5, QW9.1, U13.27
A4/SDA5: JP92.2A, JP92.2B, JP97.5, JP99.2, JP101.5, QW11.1, U16.27
A4/SDA6: JP109.2A, JP109.2B, JP114.5, JP116.2, JP118.5, QW13.1, U19.27
A4/SDA7: JP126.2A, JP126.2B, JP131.5, JP133.2, JP135.5, QW15.1, U22.27
A4/SDA8: JP143.2A, JP143.2B, JP148.5, JP150.2, JP152.5, QW17.1, U25.27
A4/SDA9: JP160.2A, JP160.2B, JP165.5, JP167.2, JP169.5, QW19.1, U28.27
A5: JP29.2, JP33.2, U2.24
A5/SCL: JP2.1A, JP2.1B, JP12.1, JP13.6, JP18.6, QW1.1, U4.28
A5/SCL1: JP24.1A, JP24.1B, JP29.6, JP31.1, JP33.6, QW4.1, U2.28
A5/SCL2: JP41.1A, JP41.1B, JP46.6, JP48.1, JP50.6, QW6.1, U7.28
A5/SCL3: JP58.1A, JP58.1B, JP63.6, JP65.1, JP67.6, QW8.1, U10.28
A5/SCL4: JP75.1A, JP75.1B, JP80.6, JP82.1, JP84.6, QW10.1, U13.28
A5/SCL5: JP92.1A, JP92.1B, JP97.6, JP99.1, JP101.6, QW12.1, U16.28
A5/SCL6: JP109.1A, JP109.1B, JP114.6, JP116.1, JP118.6, QW14.1, U19.28
A5/SCL7: JP126.1A, JP126.1B, JP131.6, JP133.1, JP135.6, QW16.1, U22.28
A5/SCL8: JP143.1A, JP143.1B, JP148.6, JP150.1, JP152.6, QW18.1, U25.28
A5/SCL9: JP160.1A, JP160.1B, JP165.6, JP167.1, JP169.6, QW20.1, U28.28
A6: J1.1, U4.19
A7: J1.2, U4.22
A8: JP29.3, JP33.3, U2.25
A9: JP29.4, JP33.4, U2.26
A10: J10.1, U2.19
A11: J10.2, U2.22
A12: JP46.1, JP50.1, U7.23
A13: JP46.2, JP50.2, U7.24
A14: JP46.3, JP50.3, U7.25
A15: JP46.4, JP50.4, U7.26
A16: J15.1, U7.19
A17: J15.2, U7.22
A18: JP63.1, JP67.1, U10.23
A19: JP63.2, JP67.2, U10.24
A20: JP63.3, JP67.3, U10.25
A21: JP63.4, JP67.4, U10.26
A22: J20.1, U10.19
A23: J20.2, U10.22
A24: JP80.1, JP84.1, U13.23
A25: JP80.2, JP84.2, U13.24
A26: JP80.3, JP84.3, U13.25
A27: JP80.4, JP84.4, U13.26
A28: J25.1, U13.19
A29: J25.2, U13.22
A30: JP97.1, JP101.1, U16.23
A31: JP97.2, JP101.2, U16.24
A32: JP97.3, JP101.3, U16.25
A33: JP97.4, JP101.4, U16.26
A34: J30.1, U16.19
A35: J30.2, U16.22
A36: JP114.1, JP118.1, U19.23
A37: JP114.2, JP118.2, U19.24
A38: JP114.3, JP118.3, U19.25
A39: JP114.4, JP118.4, U19.26
A40: J35.1, U19.19
A41: J35.2, U19.22
A42: JP131.1, JP135.1, U22.23
A43: JP131.2, JP135.2, U22.24
A44: JP131.3, JP135.3, U22.25
A45: JP131.4, JP135.4, U22.26
A46: J40.1, U22.19
A47: J40.2, U22.22
A48: JP148.1, JP152.1, U25.23
A49: JP148.2, JP152.2, U25.24
A50: JP148.3, JP152.3, U25.25
A51: JP148.4, JP152.4, U25.26
A52: J45.1, U25.19
A53: J45.2, U25.22
A54: JP165.1, JP169.1, U28.23
A55: JP165.2, JP169.2, U28.24
A56: JP165.3, JP169.3, U28.25
A57: JP165.4, JP169.4, U28.26
A58: J50.1, U28.19
A59: J50.2, U28.22
AREF: C1.1, JP2.3A, JP2.3B, JP12.3, U4.20
AREF1: C11.1, JP24.3A, JP24.3B, JP31.3, U2.20
AREF2: C31.1, JP41.3A, JP41.3B, JP48.3, U7.20
AREF3: C46.1, JP58.3A, JP58.3B, JP65.3, U10.20
AREF4: C61.1, JP75.3A, JP75.3B, JP82.3, U13.20
AREF5: C76.1, JP92.3A, JP92.3B, JP99.3, U16.20
AREF6: C91.1, JP109.3A, JP109.3B, JP116.3, U19.20
AREF7: C106.1, JP126.3A, JP126.3B, JP133.3, U22.20
AREF8: C121.1, JP143.3A, JP143.3B, JP150.3, U25.20
AREF9: C136.1, JP160.3A, JP160.3B, JP167.3, U28.20
CC1: J5.A5, R8.2
CC2: J5.B5, R7.2
CC3: J9.B5, R27.2
CC4: J9.A5, R28.2
CC5: J14.B5, R41.2
CC6: J14.A5, R42.2
CC7: J19.B5, R55.2
CC8: J19.A5, R56.2
CC9: J24.B5, R69.2
CC10: J24.A5, R70.2
CC11: J29.B5, R83.2
CC12: J29.A5, R84.2
CC13: J34.B5, R97.2
CC14: J34.A5, R98.2
CC15: J39.B5, R111.2
CC16: J39.A5, R112.2
CC17: J44.B5, R125.2
CC18: J44.A5, R126.2
CC19: J49.B5, R139.2
CC20: J49.A5, R140.2
CIPO: J2.1, JP2.6A, JP2.6B, JP12.6, TP4.P$1, U4.16
CIPO1: J6.1, JP24.6A, JP24.6B, JP31.6, TP10.P$1, U2.16
CIPO2: J11.1, JP41.6A, JP41.6B, JP48.6, TP16.P$1, U7.16
CIPO3: J16.1, JP58.6A, JP58.6B, JP65.6, TP22.P$1, U10.16
CIPO4: J21.1, JP75.6A, JP75.6B, JP82.6, TP28.P$1, U13.16
CIPO5: J26.1, JP92.6A, JP92.6B, JP99.6, TP34.P$1, U16.16
CIPO6: J31.1, JP109.6A, JP109.6B, JP116.6, TP40.P$1, U19.16
CIPO7: J36.1, JP126.6A, JP126.6B, JP133.6, TP46.P$1, U22.16
CIPO8: J41.1, JP143.6A, JP143.6B, JP150.6, TP52.P$1, U25.16
CIPO9: J46.1, JP160.6A, JP160.6B, JP167.6, TP58.P$1, U28.16
COPI: J2.4, JP2.7A, JP2.7B, JP12.7, TP2.P$1, U4.15
COPI1: J6.4, JP24.7A, JP24.7B, JP31.7, TP8.P$1, U2.15
COPI2: J11.4, JP41.7A, JP41.7B, JP48.7, TP14.P$1, U7.15
COPI3: J16.4, JP58.7A, JP58.7B, JP65.7, TP20.P$1, U10.15
COPI4: J21.4, JP75.7A, JP75.7B, JP82.7, TP26.P$1, U13.15
COPI5: J26.4, JP92.7A, JP92.7B, JP99.7, TP32.P$1, U16.15
COPI6: J31.4, JP109.7A, JP109.7B, JP116.7, TP38.P$1, U19.15
COPI7: J36.4, JP126.7A, JP126.7B, JP133.7, TP44.P$1, U22.15
COPI8: J41.4, JP143.7A, JP143.7B, JP150.7, TP50.P$1, U25.15
COPI9: J46.4, JP160.7A, JP160.7B, JP167.7, TP56.P$1, U28.15
D1: JP28.3, JP34.3, U2.32
D2: JP11.3, JP19.3, U4.32
D3: JP11.4, JP19.4, U4.1
D4: JP11.5, JP19.5, U4.2
D5: JP11.6, JP19.6, U4.9
D6: JP11.7, JP19.7, U4.10
D7: JP11.8, JP19.8, U4.11
D8: JP2.10A, JP2.10B, JP12.10, U4.12
D9: JP2.9A, JP2.9B, JP12.9, U4.13
D10: JP2.8A, JP2.8B, JP12.8, U4.14
D11: JP28.4, JP34.4, U2.1
D12: JP28.5, JP34.5, U2.2
D13: JP28.6, JP34.6, U2.9
D14: JP28.7, JP34.7, U2.10
D15: JP28.8, JP34.8, U2.11
D16: JP24.10A, JP24.10B, JP31.10, U2.12
D17: JP24.9A, JP24.9B, JP31.9, U2.13
D18: JP24.8A, JP24.8B, JP31.8, U2.14
D19: JP45.3, JP51.3, U7.32
D20: JP45.4, JP51.4, U7.1
D21: JP45.5, JP51.5, U7.2
D22: JP45.6, JP51.6, U7.9
D23: JP45.7, JP51.7, U7.10
D24: JP45.8, JP51.8, U7.11
D25: JP41.10A, JP41.10B, JP48.10, U7.12
D26: JP41.9A, JP41.9B, JP48.9, U7.13
D27: JP41.8A, JP41.8B, JP48.8, U7.14
D28: JP62.3, JP68.3, U10.32
D29: JP62.4, JP68.4, U10.1
D30: JP62.5, JP68.5, U10.2
D31: JP62.6, JP68.6, U10.9
D32: JP62.7, JP68.7, U10.10
D33: JP62.8, JP68.8, U10.11
D34: JP58.10A, JP58.10B, JP65.10, U10.12
D35: JP58.9A, JP58.9B, JP65.9, U10.13
D36: JP58.8A, JP58.8B, JP65.8, U10.14
D37: JP79.3, JP85.3, U13.32
D38: JP79.4, JP85.4, U13.1
D39: JP79.5, JP85.5, U13.2
D40: JP79.6, JP85.6, U13.9
D41: JP79.7, JP85.7, U13.10
D42: JP79.8, JP85.8, U13.11
D43: JP75.10A, JP75.10B, JP82.10, U13.12
D44: JP75.9A, JP75.9B, JP82.9, U13.13
D45: JP75.8A, JP75.8B, JP82.8, U13.14
D46: JP96.3, JP102.3, U16.32
D47: JP96.4, JP102.4, U16.1
D48: JP96.5, JP102.5, U16.2
D49: JP96.6, JP102.6, U16.9
D50: JP96.7, JP102.7, U16.10
D51: JP96.8, JP102.8, U16.11
D52: JP92.10A, JP92.10B, JP99.10, U16.12
D53: JP92.9A, JP92.9B, JP99.9, U16.13
D54: JP92.8A, JP92.8B, JP99.8, U16.14
D55: JP113.3, JP119.3, U19.32
D56: JP113.4, JP119.4, U19.1
D57: JP113.5, JP119.5, U19.2
D58: JP113.6, JP119.6, U19.9
D59: JP113.7, JP119.7, U19.10
D60: JP113.8, JP119.8, U19.11
D61: JP109.10A, JP109.10B, JP116.10, U19.12
D62: JP109.9A, JP109.9B, JP116.9, U19.13
D63: JP109.8A, JP109.8B, JP116.8, U19.14
D64: JP130.3, JP136.3, U22.32
D65: JP130.4, JP136.4, U22.1
D66: JP130.5, JP136.5, U22.2
D67: JP130.6, JP136.6, U22.9
D68: JP130.7, JP136.7, U22.10
D69: JP130.8, JP136.8, U22.11
D70: JP126.10A, JP126.10B, JP133.10, U22.12
D71: JP126.9A, JP126.9B, JP133.9, U22.13
D72: JP126.8A, JP126.8B, JP133.8, U22.14
D73: JP147.3, JP153.3, U25.32
D74: JP147.4, JP153.4, U25.1
D75: JP147.5, JP153.5, U25.2
D76: JP147.6, JP153.6, U25.9
D77: JP147.7, JP153.7, U25.10
D78: JP147.8, JP153.8, U25.11
D79: JP143.10A, JP143.10B, JP150.10, U25.12
D80: JP143.9A, JP143.9B, JP150.9, U25.13
D81: JP143.8A, JP143.8B, JP150.8, U25.14
D82: JP164.3, JP170.3, U28.32
D83: JP164.4, JP170.4, U28.1
D84: JP164.5, JP170.5, U28.2
D85: JP164.6, JP170.6, U28.9
D86: JP164.7, JP170.7, U28.10
D87: JP164.8, JP170.8, U28.11
D88: JP160.10A, JP160.10B, JP167.10, U28.12
D89: JP160.9A, JP160.9B, JP167.9, U28.13
D90: JP160.8A, JP160.8B, JP167.8, U28.14
D+: J5.A6, J5.B6, JP14.D+, U1.5
D+1: J9.A6, J9.B6, JP30.D+, U6.5
D+2: J14.A6, J14.B6, JP47.D+, U9.5
D+3: J19.A6, J19.B6, JP64.D+, U12.5
D+4: J24.A6, J24.B6, JP81.D+, U15.5
D+5: J29.A6, J29.B6, JP98.D+, U18.5
D+6: J34.A6, J34.B6, JP115.D+, U21.5
D+7: J39.A6, J39.B6, JP132.D+, U24.5
D+8: J44.A6, J44.B6, JP149.D+, U27.5
D+9: J49.A6, J49.B6, JP166.D+, U30.5
D-: J5.A7, J5.B7, JP14.D-, U1.6
D-1: J9.A7, J9.B7, JP30.D-, U6.6
D-2: J14.A7, J14.B7, JP47.D-, U9.6
D-3: J19.A7, J19.B7, JP64.D-, U12.6
D-4: J24.A7, J24.B7, JP81.D-, U15.6
D-5: J29.A7, J29.B7, JP98.D-, U18.6
D-6: J34.A7, J34.B7, JP115.D-, U21.6
D-7: J39.A7, J39.B7, JP132.D-, U24.6
D-8: J44.A7, J44.B7, JP149.D-, U27.6
D-9: J49.A7, J49.B7, JP166.D-, U30.6
GND: C1.2, C2.1, C3.-, C4.2, C5.-, C6.-, C7.2, C9.2, C10.2, C12.2, C15.-, C16.2, C17.2, C18.2, J2.6, J3.GND, J4.1, J5.GND, J5.GND2, JP2.4A, JP2.4B, JP10.2, JP10.3, JP12.4, JP14.GND, JP15.2, JP15.3, LED1.C, LED2.C, R7.1, R8.1, R14.1, S1.1, S1.2, TP3.P$1, U1.1, U3.2, U4.3, U4.5, U4.21, Y1.2, Y2.2, Y2.4
GND1: C11.2, C13.1, C14.-, C19.2, C20.-, C22.2, C23.2, C24.-, C25.-, C26.2, C27.2, C28.2, C29.2, C30.2, J6.6, J7.GND, J8.1, J9.GND, J9.GND2, JP24.4A, JP24.4B, JP25.2, JP25.3, JP30.GND, JP31.4, JP32.2, JP32.3, LED3.C, LED4.C, R19.1, R27.1, R28.1, S3.1, S3.2, TP9.P$1, U2.3, U2.5, U2.21, U5.2, U6.1, Y3.2, Y4.2, Y4.4
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

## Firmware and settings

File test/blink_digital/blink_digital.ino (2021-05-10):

void setup() {
  // put your setup code here, to run once:
  //pinMode(LED_BUILTIN, OUTPUT);
  pinMode(0, OUTPUT);
  pinMode(1, OUTPUT);
  pinMode(2, OUTPUT);
  pinMode(3, OUTPUT);
  pinMode(4, OUTPUT);
  pinMode(5, OUTPUT);
  pinMode(6, OUTPUT);
  pinMode(7, OUTPUT);
  pinMode(8, OUTPUT);
  pinMode(9, OUTPUT);
  pinMode(10, OUTPUT);
  pinMode(11, OUTPUT); 
  pinMode(12, OUTPUT);
  pinMode(13, OUTPUT);
}

void loop() {
  // put your main code here, to run repeatedly:
  digitalWrite(0, HIGH);
  digitalWrite(1, HIGH);
  digitalWrite(2, HIGH);
  digitalWrite(3, HIGH);
  digitalWrite(4, HIGH);
  digitalWrite(5, HIGH);
  digitalWrite(6, HIGH);
  digitalWrite(7, HIGH);
  digitalWrite(8, HIGH);
  digitalWrite(9, HIGH);
  digitalWrite(10, HIGH);
  digitalWrite(11, HIGH);
  digitalWrite(12, HIGH);
  digitalWrite(13, HIGH);
  delay(1000);
  digitalWrite(0, LOW);
  digitalWrite(1, LOW);
  digitalWrite(2, LOW);
  digitalWrite(3, LOW);
  digitalWrite(4, LOW);
  digitalWrite(5, LOW);
  digitalWrite(6, LOW);
  digitalWrite(7, LOW);
  digitalWrite(8, LOW);
  digitalWrite(9, LOW);
  digitalWrite(10, LOW);
  digitalWrite(11, LOW);
  digitalWrite(12, LOW);
  digitalWrite(13, LOW);
  delay(1000);
}

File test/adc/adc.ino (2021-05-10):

int val0 = 0;
int val1 = 0;
int val2 = 0;
int val3 = 0;
int val4 = 0;
int val5 = 0;
int val6 = 0;
int val7 = 0;
float volt0 = 0;
float volt1 = 0;
float volt2 = 0;
float volt3 = 0;
float volt4 = 0;
float volt5 = 0;
float volt6 = 0;
float volt7 = 0;

void setup() {
  // put your setup code here, to run once:
  Serial.begin(115200);
}

void loop() {
  // Read from analog pins
  val0 = analogRead(A0);
  val1 = analogRead(A1);
  val2 = analogRead(A2);
  val3 = analogRead(A3);
  val4 = analogRead(A4);
  val5 = analogRead(A5);
  val6 = analogRead(A6);
  val7 = analogRead(A7);

  // Convert to voltage
  volt0 = val0 * (5.0/1023.0);
  volt1 = val1 * (5.0/1023.0);
  volt2 = val2 * (5.0/1023.0);
  volt3 = val3 * (5.0/1023.0);
  volt4 = val4 * (5.0/1023.0);
  volt5 = val5 * (5.0/1023.0);
  volt6 = val6 * (5.0/1023.0);
  volt7 = val7 * (5.0/1023.0);

  // Print to serial monitor
  Serial.print("A0 voltage: ");
  Serial.println(volt0);
  Serial.print("A1 voltage: ");
  Serial.println(volt1);
  Serial.print("A2 voltage: ");
  Serial.println(volt2);
  Serial.print("A3 voltage: ");
  Serial.println(volt3);
  Serial.print("A4 voltage: ");
  Serial.println(volt4);
  Serial.print("A5 voltage: ");
  Serial.println(volt5);
  Serial.print("A6 voltage: ");
  Serial.println(volt6);
  Serial.print("A7 voltage: ");
  Serial.println(volt7);
  Serial.println();
  delay(1000); 
}

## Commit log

2021-04-06 Initial commit
    Copy files from the RedBoard Repo
    [RedBoard.brd, RedBoard.sch]
2021-04-07 Change to blackboard files
    [BlackBoard.brd, BlackBoard.sch, RedBoard.brd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]
2021-04-08 Go through DRC errors
    Updated power MOSFET to be capable of 4.2A
    Broke out A6 and A7 pins to headers
    [RedBoard.brd]
2021-04-12 Update silkscreen to vector buzzard labels
    Working on making logo vector
    [RedBoard.brd]
2021-04-13 Finished vectorizing redboard logo. Updated board files
    [RedBoard.brd, RedBoard.sch]
2021-04-13 Ran schematic and board auto-checklists
    [RedBoard.brd, RedBoard.sch]
2021-04-13 Rename eagle files to "RedBoard_Plus"
    [RedBoard_Plus.brd, RedBoard_Plus.sch]
2021-04-13 Remove reference layer from redboard logo. Remove layers 2 and 15 from board
    [RedBoard_Plus.brd]
2021-04-13 Pete's design review notes:
    SF logo on back
    GND vias next to USB C
    Remove 4-way nodes on sch
    Remove overlapping text on sch
    Move SFE logo in sch
    Sch typo
    [RedBoard_Plus.brd, RedBoard_Plus.sch]
2021-04-13 Design review changes
    [RedBoard_Plus.brd, RedBoard_Plus.sch]
2021-04-14 Switch CH340C for CH340G with external oscillator
    [RedBoard_Plus.brd, RedBoard_Plus.sch]
2021-04-15 Update silkscreen
    Increased the size of PTH labels on back side to all be the same size
    Added "(PLUS)" label to board name - top/bottom
    Vector-ized "ELECTRONICS"
    [RedBoard_Plus.brd]
2021-04-15 Run checklist
    [RedBoard_Plus.brd]
2021-04-15 Change "I/O" label to "Logic" and make A4/A5 jumper labels inverted pill-shape
    [RedBoard_Plus.brd]
2021-04-16 Add "DNP" to headers on schematic
    [RedBoard_Plus.brd, RedBoard_Plus.sch]
2021-04-19 QC Double check changes
    [RedBoard_Plus.brd, RedBoard_Plus.sch]
2021-04-19 Update "GND" Buzzard labels
    [RedBoard_Plus.brd]
2021-04-19 Follow Up review changes
    Added Qwiic logo device to schematic
    Switch RXO/TXI signals at CH340G. Switched the order of LEDs as well
    Updated headers to use current library parts
    Updated ISP header sch symbol to use COPI/CIPO
    [RedBoard_Plus.brd, RedBoard_Plus.sch]
2021-04-19 Generate CAM files
    [RedBoard_Plus.GBL, RedBoard_Plus.GBO, RedBoard_Plus.GBP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]
2021-04-22 Update prod_id on isp header
    [RedBoard_Plus.brd, RedBoard_Plus.sch]
2021-05-13 Run engineering checklist
    Changes made:
    Flipped the V10 on the board edge
    Changed the 2 VCC flags in the schematic to power symbols
    Added the RedBoard logo to the SF Aesthetics library and replaced the device in the schematic
    [RedBoard_Plus.brd, RedBoard_Plus.sch]
2021-05-13 Add the Arduino attribution to the board file and redraw dimensions
    [RedBoard_Plus.brd, RedBoard_Plus.sch]
2021-05-14 Update silk on bottom of board
    Move "1" label more in-line with others
    Add "~" to pins 10 and 11
    [RedBoard_Plus.brd]
2021-05-14 Remove CAM files for single PCB
    [RedBoard_Plus.GBL, RedBoard_Plus.GBO, RedBoard_Plus.GBP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]
2021-05-17 Update panel
    [RedBoard_Plus-Panel.brd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]
2021-05-17 Re-panelize without fiducials moved to left+right corners
    [RedBoard_Plus-Panel.brd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]
2021-07-02 Update RedBoard_Plus.brd
    Minor update to board file to that adds two more measurements for board dimensions
    [RedBoard_Plus.brd]

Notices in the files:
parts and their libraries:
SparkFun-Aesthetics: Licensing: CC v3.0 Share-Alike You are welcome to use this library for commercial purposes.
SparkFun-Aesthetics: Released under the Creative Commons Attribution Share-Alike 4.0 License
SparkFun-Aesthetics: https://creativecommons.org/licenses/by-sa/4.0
